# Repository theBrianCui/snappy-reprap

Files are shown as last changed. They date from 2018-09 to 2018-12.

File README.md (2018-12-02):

Snappy Full Rendering

Snappy-Reprap 3 Prime
===============

Snappy3 Prime is a variant of Snappy 3 with some model tweaks and firmware changes.

## Firmware Changes

 - All endstops have been inverted, so the endstops correctly report "unpressed" when they are not pressed. Before inversion, the endstops appeared to report "pressed" when they were unpressed, and the motors would refuse to turn backwards (believing the axis was at-home).
 - Heated bed support is disabled. The heated bed thermistor is inactive and overheating protections for the heated bed are off.

## Hardware Choices

 - Endstops: [Gowoops 5 PCS Mechanical Endstop Switch with Cable](https://amzn.to/2ScCRdb)
 - Glass Bed: [Signstek 3D Printer MK2 MK3 Heated Bed Tempered Borosilicate Glass Plate 213x200x3mm](https://www.amazon.com/gp/product/B00QQ5Q3BI/ref=oh_aui_detailpage_o03_s00?ie=UTF8&psc=1)

## Compiling Firmware

The firmware source code is in the `firmware/marlin` directory. To compile and upload the firmware to the Arduino Mega 2560 board, you will need the Arduino IDE with the U8glib library plugin installed. Check out the [RepRap Wiki](https://reprap.org/wiki/Marlin#Configuring_and_compilation) for more details.

## Model Changes

 - X and Y axis motor cages have thinner walls to allow stepper motors with extended cable ports to fit through.
 - Glass bed supports have been slightly extended for a tight fit on the glass bed.
 - The extruder fan clip cover has been removed for less restricted airflow. The updated STL is saved in `STLs/extruder_fan_clip_no_cover_parts.stl`.
 - Two endstops are required for each rail of the Z axis (not specified in the assembly instructions). These allow the two motors/rail segments to normalize independently.

## Original README

A parametric design for a cheap self-replicating 3D printer (reprap) that snaps together to minimize screws and non-printed parts.

Important Links:

What                 | URL
-------------------- | -------------------------------------------------------
GitHub Repository    | https://github.com/revarbat/snappy-reprap
Project Wiki         | https://github.com/revarbat/snappy-reprap/wiki/v3.0-Home
Bill of Materials    | https://github.com/revarbat/snappy-reprap/wiki/v3.0-BOM
How to Assemble      | https://github.com/revarbat/snappy-reprap/wiki/v3.0-Assembly
RepRap.org Wiki Page | http://reprap.org/wiki/Snappy
Dev Forum            | https://groups.google.com/forum/#!forum/snappy-reprap-dev



Generating STL Files
====================
For all platforms, you will need to have OpenSCAD installed. You can download OpenSCAD from their website at [http://www.openscad.org](http://www.openscad.org)

OS X:
-----
Under OS X, you'll need to make sure you have the Xcode command-line tools installed first.  You can get them by installing Xcode from the App Store.

You shouldn't need to change the Makefile.  It should set $OPENSCAD as:
```
OPENSCAD=/Applications/OpenSCAD.app/Contents/MacOS/OpenSCAD
```

To generate the STL model files, open a terminal to the snappy-reprap directory and type:
```
make
```

Linux:
------
Under Linux, you will need to edit the Makefile, and change $OPENSCAD to:
```
OPENSCAD=openscad
```
To generate the STL model files, open a terminal to the snappy-reprap directory and type:
```
make
```

Windows:
--------
Under Windows, you'll probably have to open and compile each `*_parts.scad` file individually and manually export the STL files.

You _might_ be able to run the makefile under CygWin, if you set $OPENSCAD to something like:
```
OPENSCAD="/Program Files/OpenSCAD/openscad.exe"
```

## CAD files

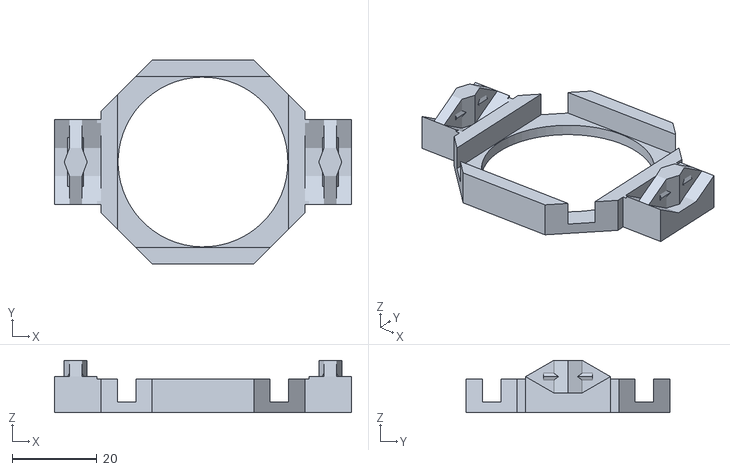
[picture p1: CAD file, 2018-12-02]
STLs/extruder_fan_clip_no_cover_parts.stl
70.0 x 48.0 x 12.3

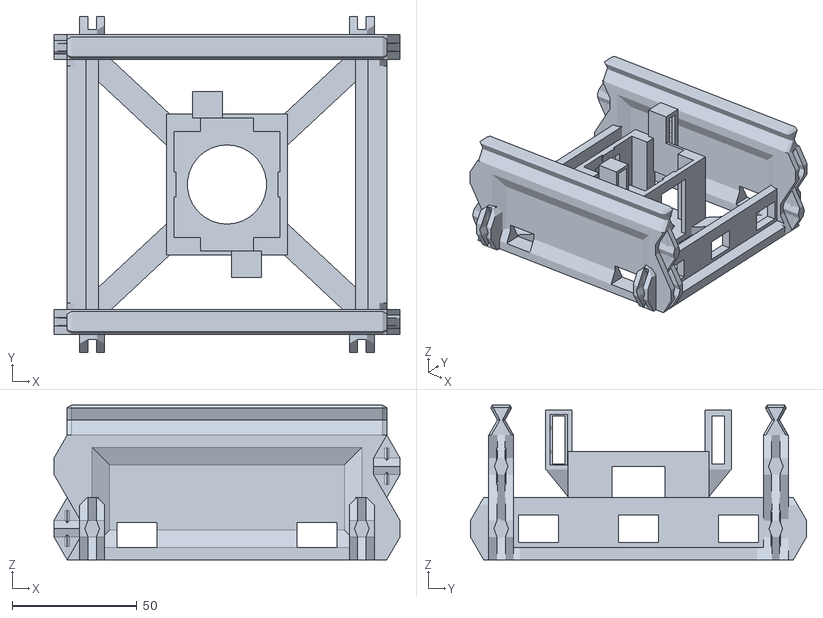
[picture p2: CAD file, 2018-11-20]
STLs/rail_xy_motor_segment_parts.stl
138.6 x 134.6 x 62.0

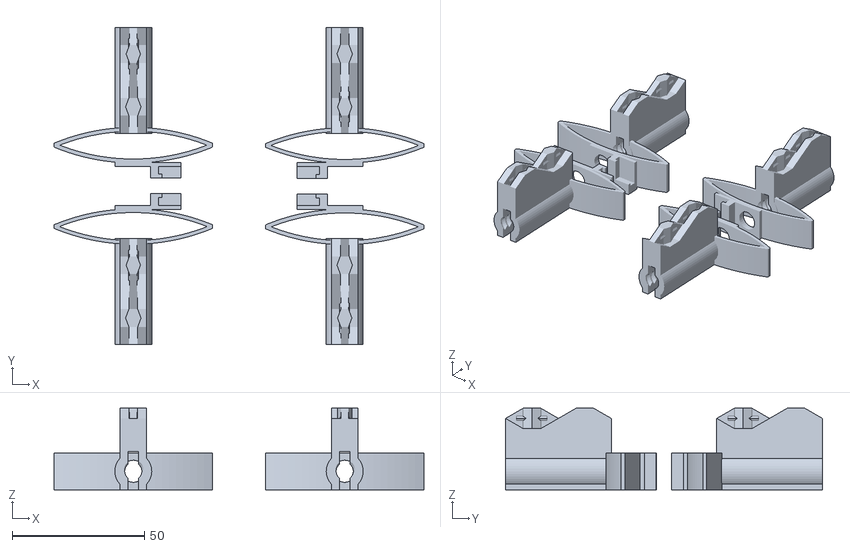
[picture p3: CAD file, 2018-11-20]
STLs/glass_bed_support_parts.stl
140.0 x 119.9 x 30.8

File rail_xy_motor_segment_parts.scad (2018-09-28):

include <config.scad>
use <GDMUtils.scad>
use <sliders.scad>
use <joiners.scad>
use <NEMA.scad>


// connectby valid options: "", "fwd", "back"
module rail_xy_motor_segment(explode=0, connectby="")
{
	joiner_length = 8;
	side_joiner_len = 2;
	motor_width = nema_motor_width(17);

	up(
		(connectby=="fwd")? -rail_height/2 :
		(connectby=="back")? -rail_height/2 :
		0
	) back(
		(connectby=="back")? -motor_rail_length/2 :
		(connectby=="fwd")? motor_rail_length/2 :
		0
	) {
		color("SpringGreen")
		prerender(convexity=20)
		union() {
			difference() {
				union() {
					// Bottom.
					up(rail_thick/2) {
						difference() {
							union() {
								yrot(90) sparse_strut(h=rail_width, l=motor_rail_length, thick=rail_thick, maxang=75, strut=10, max_bridge=500);
								up((motor_top_z-motor_length+6-rail_thick)/2) {
									cube(size=[motor_width+2*7, motor_width+2*3, motor_top_z-motor_length+6], center=true);
								}
								up(motor_top_z-rail_thick/2) {
									down(motor_length/2) {
										cube(size=[motor_width+2*7, motor_width+2*3, motor_length+2*1], center=true);
									}
								}
							}

							// Clearance for NEMA17 stepper motor
							up(motor_top_z-rail_thick/2-motor_length/2) {
								up(2/2+0.05) {
									difference() {
										cube(size=[motor_width+printer_slop, motor_width+printer_slop, motor_length+printer_slop+2], center=true);
										up(motor_length/2) {
											yspread(motor_width+2*printer_slop) {
												cube(size=[10, 2, 2], center=true);
												cube(size=[10, 1, 8], center=true);
											}
										}
									}
								}
								down(5/2) cube(size=[motor_width/2, motor_width+20, motor_length-5], center=true);
								down(motor_length/2/2) cube(size=[motor_width+20, motor_width/2, motor_length/2], center=true);
								up(5/2) cube(size=[motor_width+2*4+3, motor_width/2, motor_length+5], center=true);
								cylinder(d=motor_width*3/4, h=motor_length*2, center=true);
							}
						}
					}

					// Walls.
					zring(r=0,n=2) {
						up(rail_height/2) {
							right((rail_spacing+joiner_width)/2) {
								if (wall_style == "crossbeams")
									sparse_strut(h=rail_height, l=motor_rail_length-10, thick=joiner_width, strut=5);
								if (wall_style == "thinwall")
									thinning_wall(h=rail_height, l=motor_rail_length-10, thick=joiner_width, strut=5);
								if (wall_style == "corrugated")
									corrugated_wall(h=rail_height, l=motor_rail_length-10, thick=joiner_width, strut=5);
							}
						}
					}

					// Rails.
					xspread(rail_spacing+joiner_width) {
						up(rail_height+groove_height/2-0.01) {
							rail(l=motor_rail_length, w=joiner_width-0.01, h=groove_height);
						}
					}

					// Side Supports
					up(rail_height/4) {
						yspread(motor_rail_length-20) {
							cube(size=[rail_width, 5, rail_height/2], center=true);
						}
					}

					// Endstop clip
					zrot_copies([0, 180]) {
						fwd((endstop_depth+2)/2-drive_gear_diam/2) {
							right((motor_width+endstop_thick+3+2*7)/2) {
								up(rail_height+groove_height-2-(endstop_length+2*2)/2) {
									difference() {
										left(2/2) cube([endstop_thick+4, endstop_depth+2, endstop_length+2*2], center=true);
										left(2/2) back(2/2) {
											cube([endstop_thick+2*printer_slop+0.05, endstop_depth+0.05, endstop_length+2*printer_slop], center=true);
											cube([endstop_thick+2*printer_slop-2, endstop_depth+10, endstop_length+2*printer_slop-1], center=true);
										}
									}
									down(endstop_length/2+2+endstop_thick*1.8/2-0.05) {
										left((endstop_thick+4.1)/2) {
											right_half() trapezoid([0.05, 0.05], [2*(endstop_thick+2)+2, endstop_depth+2], h=endstop_thick*1.8, center=true);
										}
									}
									zspread(endstop_hole_spacing) {
										right(endstop_thick/2-1.5/2+0.05) {
											back(endstop_depth/2+2/2-endstop_hole_inset) {
												scale([0.5, 1, 1]) {
													sphere(d=endstop_screw_size, center=true, $fn=8);
												}
											}
										}
									}
								}
							}
						}
					}

					// Side wiring access hole frame
					if (wall_style == "corrugated") {
						up(10/2+rail_thick) {
							xspread(rail_width-joiner_width) {
								yspread(motor_rail_length-2*28) {
									cube(size=[joiner_width, 16+4, 10+4], center=true);
								}
							}
						}
					}
				}

				// Wiring access holes.
				up(rail_height/4) {
					xspread(rail_width/3, n=3) {
						yspread(motor_rail_length-20) {
							cube(size=[16, 11, 11], center=true);
						}
					}
				}

				// Clear space for joiners.
				up(rail_height/2) {
					joiner_quad_clear(xspacing=rail_spacing+joiner_width, yspacing=motor_rail_length-0.05, h=rail_height, w=joiner_width, clearance=5, a=joiner_angle);
				}

				// Side wiring access hole
				if (wall_style != "crossbeams") {
					up(10/2+rail_thick) {
						xspread(rail_width-joiner_width) {
							yspread(motor_rail_length-2*28) {
								cube(size=[joiner_width+1, 16, 10], center=true);
							}
						}
					}
				}

				// Clear space for Side half joiners
				up(rail_height/2/2) {
					yspread(side_mount_spacing) {
						zring(r=rail_spacing/2+joiner_width+side_joiner_len-0.05, n=2) {
							zrot(-90) {
								chamfer(chamfer=3, size=[joiner_width, 2*(side_joiner_len+joiner_width/2), rail_height/2], edges=[[0,0,0,0], [1,1,0,0], [0,0,0,0]]) {
									half_joiner_clear(h=rail_height/2, w=joiner_width, a=joiner_angle);
								}
							}
						}
					}
				}
			}

			// Snap-tab joiners.
			up(rail_height/2) {
				joiner_quad(xspacing=rail_spacing+joiner_width, yspacing=motor_rail_length, h=rail_height, w=joiner_width, l=6, a=joiner_angle);
			}

			// Side half joiners
			up(rail_height/2/2) {
				yspread(side_mount_spacing) {
					zring(r=rail_spacing/2+joiner_width+side_joiner_len, n=2) {
						zrot(-90) {
							chamfer(chamfer=3, size=[joiner_width, 2*(side_joiner_len+joiner_width/2), rail_height/2], edges=[[0,0,0,0], [1,1,0,0], [0,0,0,0]]) {
								half_joiner2(h=rail_height/2, w=joiner_width, l=side_joiner_len+joiner_width/2, a=joiner_angle);
							}
						}
					}
				}
			}
		}
		up(motor_top_z-motor_length/2+explode) {
			if ($children > 0) children(0);
		}
		up(rail_height/2) {
			fwd(motor_rail_length/2+explode) {
				if ($children > 1) children(1);
			}
			back(motor_rail_length/2+explode) {
				if ($children > 2) children(2);
			}
		}
	}
}
//!rail_xy_motor_segment();



module rail_xy_motor_segment_parts() { // make me
	zrot(90) rail_xy_motor_segment();
}


rail_xy_motor_segment_parts();



// vim: noexpandtab tabstop=4 shiftwidth=4 softtabstop=4 nowrap

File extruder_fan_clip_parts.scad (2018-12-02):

include <config.scad>
use <GDMUtils.scad>
use <joiners.scad>


$fa = 2;
$fs = 2;

h = 6;
thick = 8;
inset = thick-2.5;


module extruder_fan_clip()
{
	color("violet")
	prerender(convexity=10)
	union() {
		difference() {
			union() {
				// Base
				up(h-inset+thick/2) {
					difference() {
						union() {
							chamfcube([extruder_fan_size+8, extruder_fan_size+8, thick], chamfer=12, chamfaxes=[0,0,1], center=true);
							cube([extruder_fan_size+3*joiner_width, extruder_fan_size/2, thick], center=true);
						}
						cylinder(d=extruder_fan_size, h=100, center=true);
						down(thick/2) {
							cube([extruder_fan_size+2*printer_slop, extruder_fan_size+2*printer_slop, inset*2], center=true);
						}
					}
					/*up((inset+1)/2) {
						cylinder(d=extruder_fan_size/2-4, h=thick-inset-1, center=true);
						zring(n=4, r=extruder_fan_size/4) {
							cube([extruder_fan_size/2+1, 3, thick-inset-1], center=true);
						}
					}*/
				}
			}

			// Fan clip joiner clearance
			xspread(extruder_fan_size+2*joiner_width) {
				xrot(-90) half_joiner_clear(h=extruder_fan_size/2, w=joiner_width, a=joiner_angle, clearance=2);
			}
		}

		// Fan clip Joiners
		xspread(extruder_fan_size+2*joiner_width) {
			xrot(-90) half_joiner(h=extruder_fan_size/2, w=joiner_width, l=h+thick-inset, a=joiner_angle);
		}
	}
}



module extruder_fan_clip_parts() { // make me
	up(h+thick-inset) xrot(180) extruder_fan_clip();
}



extruder_fan_clip_parts();



// vim: noexpandtab tabstop=4 shiftwidth=4 softtabstop=4 nowrap

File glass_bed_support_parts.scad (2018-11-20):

include <config.scad>
use <GDMUtils.scad>
use <joiners.scad>
use <acme_screw.scad>


$fa = 2;
$fs = 1;


module glass_bed_support1()
{
	glass_xoff = (2*platform_length + 2*20 - joiner_width - glass_length) / 2;
	backing_diam = adjust_screw_diam + 2*3;
	l = (glass_width-platform_width)/2 + 2;
	w = glass_xoff + backing_diam/2 + 10;
	h = glass_thick + 3;
	l2 = l - backing_diam/2;
	spring_h = 12;
	spring_w = 60;
	spring_thick = 1.4;

	color("Chocolate")
	prerender(convexity=10)
	down(platform_height/2-0.05) {
		difference() {
			union() {
				// Joiner.
				joiner(h=platform_height, w=joiner_width, l=l, a=joiner_angle);

				// Clip platform
				fwd(l2) {
					up(platform_height/2+spring_h-spring_thick/2) {
						cube(size=[backing_diam, backing_diam, spring_thick], center=true);
						up(h/2-0.25) {
							difference() {
								left(w/2-backing_diam/2) {
									cube(size=[w, backing_diam, h], center=true);
								}

								// glass mount slot
								left(50/2+glass_xoff-printer_slop + 1.75) { // CHANGE LENGTH
									back(2-printer_slop + 1.75 + .5) { // CHANGE WIDTH
										cube(size=[50, backing_diam + .5, glass_thick], center=true); // CHANGE WIDTH COVER
										up(glass_thick-0.05) back(1) left(1) cube(size=[50 - .5, backing_diam, glass_thick], center=true); // CHANGE LENGTH COVER COVER
									}
								}

								// Screw head clearance
								up(1.5) right(2/2) cube(size=[adjust_screw_knob_d+3, backing_diam+1, h], center=true);
							}
						}
					}
				}

				// Screw hole backing
				fwd(l2) {
					cylinder(d=backing_diam, h=platform_height, center=true);
				}

				// Leaf spring
				spring_r = spring_h/4 + spring_w * spring_w / 4 / spring_h;
				fwd(l2) {
					up(platform_height/2+spring_h/2-spring_thick) {
						xrot(90) {
							difference() {
								yflip_copy() {
									fwd(0.01) {
										back_half(spring_r*3) {
											fwd(spring_r-spring_thick/2-spring_h/2) {
												tube(h=backing_diam, r=spring_r, wall=spring_thick, center=true);
											}
										}
									}
								}
								xspread(spring_w+10) cube(size=[10, spring_h, backing_diam+1], center=true);
							}
						}
					}
				}
			}

			fwd(l2) {
				// Threaded hole
				acme_threaded_rod(d=adjust_screw_diam+2*printer_slop, l=platform_height*1.2, thread_depth=adjust_thread_depth, pitch=adjust_screw_pitch, thread_angle=adjust_screw_angle);

				// bevel threaded hole
				up(platform_height/2+0.2) {
					cylinder(d1=adjust_screw_diam-2*adjust_thread_depth, d2=adjust_screw_diam+2, h=2*adjust_thread_depth, center=true);
				}

				// gap
				cube(size=[adjust_screw_diam/2, adjust_screw_diam+2*3+1, platform_height*1.1], center=true);

				// Unthreaded hole
				up(platform_height/2+spring_h) {
					cylinder(d=adjust_screw_diam+2*printer_slop, h=h*2, center=true);
				}
			}
		}
	}
}
//!glass_bed_support1();



module glass_bed_support2()
{
	glass_xoff = (2*platform_length + 2*20 - joiner_width - glass_length) / 2;
	backing_diam = adjust_screw_diam + 2*3;
	l = (glass_width-platform_width)/2 + 2;
	w = glass_xoff + backing_diam/2 + 10;
	h = glass_thick + 3;
	l2 = l - backing_diam/2;
	spring_h = 12;
	spring_w = 60;
	spring_thick = 1.5;

	color("Chocolate")
	prerender(convexity=10)
	down(platform_height/2-0.05) {
		difference() {
			union() {
				// Joiner.
				yrot(180) joiner(h=platform_height, w=joiner_width, l=l, a=joiner_angle);

				// Clip platform
				fwd(l2) {
					up(platform_height/2+spring_h-spring_thick/2) {
						cube(size=[backing_diam, backing_diam, spring_thick], center=true);
						up(h/2-0.25) {
							difference() {
								right(w/2-backing_diam/2) {
									cube(size=[w, backing_diam, h], center=true);
								}

								// glass mount slot
								right(50/2+glass_xoff-printer_slop + 1.75) {
									back(2-printer_slop + 1.75 + .5) {
										cube(size=[50, backing_diam + .5, glass_thick], center=true);
										up(glass_thick-0.05) back(1) right(1) cube(size=[50 - .5, backing_diam, glass_thick], center=true);
									}
								}

								// Screw head clearance
								up(1.5) left(2/2) cube(size=[adjust_screw_knob_d+3, backing_diam+1, h], center=true);
							}
						}
					}
				}

				// Screw hole backing
				fwd(l2) {
					cylinder(d=backing_diam, h=platform_height, center=true);
				}

				// Leaf spring
				spring_r = spring_h/4 + spring_w * spring_w / 4 / spring_h;
				fwd(l2) {
					up(platform_height/2+spring_h/2-spring_thick) {
						xrot(90) {
							difference() {
								yflip_copy() {
									fwd(0.01) {
										back_half(spring_r*3) {
											fwd(spring_r-spring_thick/2-spring_h/2) {
												tube(h=backing_diam, r=spring_r, wall=spring_thick, center=true);
											}
										}
									}
								}
								xspread(spring_w+10) cube(size=[10, spring_h, backing_diam+1], center=true);
							}
						}
					}
				}
			}

			fwd(l2) {
				// Threaded hole
				acme_threaded_rod(d=adjust_screw_diam+2*printer_slop, l=platform_height*1.2, thread_depth=adjust_thread_depth, pitch=adjust_screw_pitch, thread_angle=adjust_screw_angle);

				// bevel threaded hole
				up(platform_height/2+0.2) {
					cylinder(d1=adjust_screw_diam-2*adjust_thread_depth, d2=adjust_screw_diam+2, h=2*adjust_thread_depth, center=true);
				}

				// gap
				cube(size=[adjust_screw_diam/2, adjust_screw_diam+2*3+1, platform_height*1.1], center=true);

				// Unthreaded hole
				up(platform_height/2+spring_h) {
					cylinder(d=adjust_screw_diam+2*printer_slop, h=h*2, center=true);
				}
			}
		}
	}
}
//!glass_bed_support2();



module glass_bed_support_parts() { // make me
	l = (glass_width-platform_width)/2 + 2;
	zrot_copies([0, 180]) {
		up(l) {
			back(20) {
				left(40) xrot(90) glass_bed_support2();
				right(40) xrot(90) glass_bed_support1();
			}
		}
	}
}

glass_bed_support_parts();



// vim: noexpandtab tabstop=4 shiftwidth=4 softtabstop=4 nowrap

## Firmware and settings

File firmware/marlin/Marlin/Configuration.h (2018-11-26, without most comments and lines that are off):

#define CONFIGURATION_H
#define CONFIGURATION_H_VERSION 010100
#define STRING_CONFIG_H_AUTHOR "(RevarBat, Snappy config)" // Who made the changes.
#define SHOW_BOOTSCREEN
#define STRING_SPLASH_LINE1 SHORT_BUILD_VERSION // will be shown during bootup in line 1
#define STRING_SPLASH_LINE2 WEBSITE_URL         // will be shown during bootup in line 2
#define SERIAL_PORT 0
#define BAUDRATE 250000
  #define MOTHERBOARD BOARD_RAMPS_14_EFB
#define CUSTOM_MACHINE_NAME "Snappy3 Prime"
#define EXTRUDERS 1
#define POWER_SUPPLY 0
#define TEMP_SENSOR_0 1
#define TEMP_SENSOR_1 0
#define TEMP_SENSOR_2 0
#define TEMP_SENSOR_3 0
#define TEMP_SENSOR_4 0
#define TEMP_SENSOR_BED 0
#define DUMMY_THERMISTOR_998_VALUE 25
#define DUMMY_THERMISTOR_999_VALUE 100
#define MAX_REDUNDANT_TEMP_SENSOR_DIFF 10
#define TEMP_RESIDENCY_TIME 10  // (seconds)
#define TEMP_HYSTERESIS 3       // (degC) range of +/- temperatures considered "close" to the target one
#define TEMP_WINDOW     1       // (degC) Window around target to start the residency timer x degC early.
#define TEMP_BED_RESIDENCY_TIME 10  // (seconds)
#define TEMP_BED_HYSTERESIS 3       // (degC) range of +/- temperatures considered "close" to the target one
#define TEMP_BED_WINDOW     1       // (degC) Window around target to start the residency timer x degC early.
#define HEATER_0_MINTEMP 5
#define HEATER_1_MINTEMP 5
#define HEATER_2_MINTEMP 5
#define HEATER_3_MINTEMP 5
#define HEATER_4_MINTEMP 5
#define BED_MINTEMP 5
#define HEATER_0_MAXTEMP 275
#define HEATER_1_MAXTEMP 275
#define HEATER_2_MAXTEMP 275
#define HEATER_3_MAXTEMP 275
#define HEATER_4_MAXTEMP 275
#define BED_MAXTEMP 150
#define PIDTEMP
#define BANG_MAX 255 // limits current to nozzle while in bang-bang mode; 255=full current
#define PID_MAX BANG_MAX // limits current to nozzle while PID is active (see PID_FUNCTIONAL_RANGE below); 255=full current
  #define PID_AUTOTUNE_MENU // Add PID Autotune to the LCD "Temperature" menu to run M303 and apply the result.
  #define PID_FUNCTIONAL_RANGE 10 // If the temperature difference between the target temperature and the actual temperature
  #define K1 0.95 //smoothing factor within the PID
  #define  DEFAULT_Kp 29.42
  #define  DEFAULT_Ki 1.81
  #define  DEFAULT_Kd 119.36
#define MAX_BED_POWER 255 // limits duty cycle to bed; 255=full current
#define PREVENT_COLD_EXTRUSION
#define EXTRUDE_MINTEMP 170
#define PREVENT_LENGTHY_EXTRUDE
#define EXTRUDE_MAXLENGTH 200
#define THERMAL_PROTECTION_HOTENDS // Enable thermal protection for all extruders
#define USE_XMIN_PLUG
#define USE_YMIN_PLUG
#define USE_ZMIN_PLUG
#define USE_ZMAX_PLUG
#define ENDSTOPPULLUPS // Comment this out (using // at the start of the line) to disable the endstop pullup resistors
#define X_MIN_ENDSTOP_INVERTING true // set to true to invert the logic of the endstop.
#define Y_MIN_ENDSTOP_INVERTING true // set to true to invert the logic of the endstop.
#define Z_MIN_ENDSTOP_INVERTING true // set to true to invert the logic of the endstop.
#define X_MAX_ENDSTOP_INVERTING true // set to true to invert the logic of the endstop.
#define Y_MAX_ENDSTOP_INVERTING true // set to true to invert the logic of the endstop.
#define Z_MAX_ENDSTOP_INVERTING true // set to true to invert the logic of the endstop.
#define Z_MIN_PROBE_ENDSTOP_INVERTING false // set to true to invert the logic of the probe.
#define ENDSTOP_INTERRUPTS_FEATURE
#define DEFAULT_AXIS_STEPS_PER_UNIT   { 40, 40, 400, 96 }
#define DEFAULT_MAX_FEEDRATE          { 150, 150, 5, 25 }
#define DEFAULT_MAX_ACCELERATION      { 1000, 1000, 10, 10000 }
#define DEFAULT_ACCELERATION          400    // X, Y, Z and E acceleration for printing moves
#define DEFAULT_RETRACT_ACCELERATION  1000    // E acceleration for retracts
#define DEFAULT_TRAVEL_ACCELERATION   600    // X, Y, Z acceleration for travel (non printing) moves
#define DEFAULT_XJERK                  5.0
#define DEFAULT_YJERK                  5.0
#define DEFAULT_ZJERK                  0.4
#define DEFAULT_EJERK                  3.0
#define X_PROBE_OFFSET_FROM_EXTRUDER 10  // X offset: -left  +right  [of the nozzle]
#define Y_PROBE_OFFSET_FROM_EXTRUDER 10  // Y offset: -front +behind [the nozzle]
#define Z_PROBE_OFFSET_FROM_EXTRUDER 0   // Z offset: -below +above  [the nozzle]
#define XY_PROBE_SPEED 8000
#define Z_PROBE_SPEED_FAST HOMING_FEEDRATE_Z
#define Z_PROBE_SPEED_SLOW (Z_PROBE_SPEED_FAST / 2)
#define Z_CLEARANCE_DEPLOY_PROBE   10 // Z Clearance for Deploy/Stow
#define Z_CLEARANCE_BETWEEN_PROBES  5 // Z Clearance between probe points
#define Z_PROBE_OFFSET_RANGE_MIN -20
#define Z_PROBE_OFFSET_RANGE_MAX 20
#define X_ENABLE_ON 0
#define Y_ENABLE_ON 0
#define Z_ENABLE_ON 0
#define E_ENABLE_ON 0 // For all extruders
#define DISABLE_X false
#define DISABLE_Y false
#define DISABLE_Z false
#define DISABLE_E false // For all extruders
#define DISABLE_INACTIVE_EXTRUDER true // Keep only the active extruder enabled.
#define INVERT_X_DIR false
#define INVERT_Y_DIR false
#define INVERT_Z_DIR true
#define INVERT_E0_DIR true
#define INVERT_E1_DIR false
#define INVERT_E2_DIR false
#define INVERT_E3_DIR false
#define INVERT_E4_DIR false
#define X_HOME_DIR -1
#define Y_HOME_DIR -1
#define Z_HOME_DIR -1
#define X_BED_SIZE 198
#define Y_BED_SIZE 198
#define X_MIN_POS 0
#define Y_MIN_POS 0
#define Z_MIN_POS 0
#define X_MAX_POS X_BED_SIZE
#define Y_MAX_POS Y_BED_SIZE
#define Z_MAX_POS 220
#define MIN_SOFTWARE_ENDSTOPS
#define MAX_SOFTWARE_ENDSTOPS
#define LEVEL_BED_CORNERS
#define HOMING_FEEDRATE_XY (50*60)
#define HOMING_FEEDRATE_Z  (4*60)
#define EEPROM_SETTINGS // Enable for M500 and M501 commands
#define EEPROM_CHITCHAT   // Give feedback on EEPROM commands. Disable to save PROGMEM.
#define HOST_KEEPALIVE_FEATURE        // Disable this if your host doesn't like keepalive messages
#define DEFAULT_KEEPALIVE_INTERVAL 2  // Number of seconds between "busy" messages. Set with M113.
#define BUSY_WHILE_HEATING            // Some hosts require "busy" messages even during heating
#define PREHEAT_1_TEMP_HOTEND 220
#define PREHEAT_1_TEMP_BED     50
#define PREHEAT_1_FAN_SPEED     0 // Value from 0 to 255
#define PREHEAT_2_TEMP_HOTEND 240
#define PREHEAT_2_TEMP_BED    100
#define PREHEAT_2_FAN_SPEED     0 // Value from 0 to 255
#define PRINTJOB_TIMER_AUTOSTART
#define LCD_LANGUAGE en
#define DISPLAY_CHARSET_HD44780 JAPANESE
#define DOGLCD      // Full graphics display
#define SDSUPPORT
#define SD_CHECK_AND_RETRY
#define ENCODER_PULSES_PER_STEP 4
#define REVERSE_ENCODER_DIRECTION
#define INDIVIDUAL_AXIS_HOMING_MENU
#define REPRAP_DISCOUNT_FULL_GRAPHIC_SMART_CONTROLLER
#define SOFT_PWM_SCALE 0
#define SERVO_DELAY { 300 }
#define DEFAULT_NOMINAL_FILAMENT_DIA 1.75   // (mm) Diameter of the filament generally used (3.0 or 1.75mm), also used in the slicer. Used to validate sensor reading.

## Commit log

2018-09-28 Increased width of stepper motor cage to better fit wiring protrusions
    [rail_xy_motor_segment_parts.scad]
2018-11-20 reduce dimensions of glass bed to fit glass
    [glass_bed_support_parts.scad]
2018-11-20 update STLs
    [glass_bed_support_parts.stl, rail_xy_motor_segment_parts.stl]
2018-11-26 add unzipped marlin firmware
    [Configuration.h, Configuration_adv.h]
2018-11-26 Disable thermal protection for heated bed, no heated bed in use
    [Configuration.h]
2018-11-26 add graphics display and SD card support
    [Configuration.h]
2018-11-26 Inverted x, y, z endstops
    [Configuration.h]
2018-11-26 invert all endstops
    [Configuration.h]
2018-11-26 Add more details to endstop inversion in README
2018-12-02 Removed cover on extruder fan clip for less air resistance
    [extruder_fan_clip_no_cover_parts.stl, extruder_fan_clip_parts.scad]

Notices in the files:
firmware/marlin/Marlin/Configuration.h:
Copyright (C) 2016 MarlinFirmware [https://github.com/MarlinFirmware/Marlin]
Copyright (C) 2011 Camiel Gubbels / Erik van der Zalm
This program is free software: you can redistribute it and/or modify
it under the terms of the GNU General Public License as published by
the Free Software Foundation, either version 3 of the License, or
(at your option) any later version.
